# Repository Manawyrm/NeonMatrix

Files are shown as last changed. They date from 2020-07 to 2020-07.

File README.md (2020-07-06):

NeonMatrix
=============================

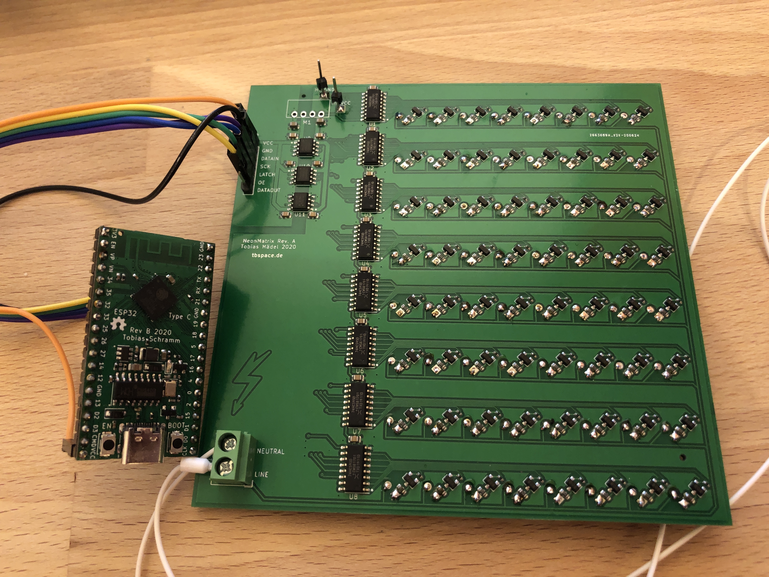
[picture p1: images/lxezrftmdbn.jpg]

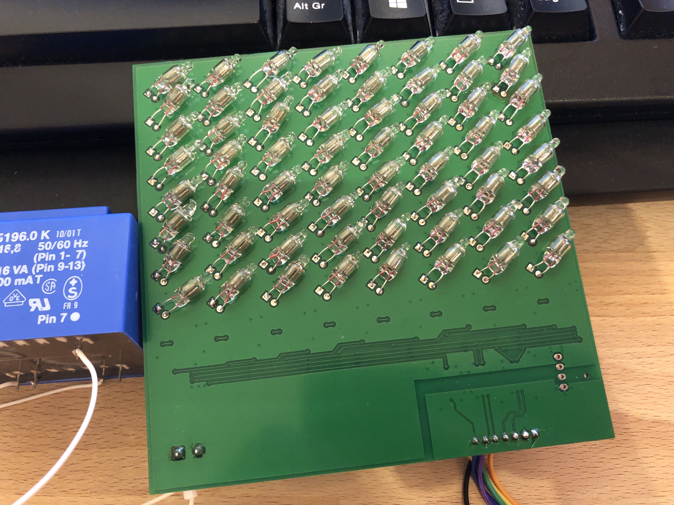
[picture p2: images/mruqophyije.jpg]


#### Overview

The NeonMatrix 8x8 matrix uses common neon indicator bulbs to display simple graphics.  
They can be chained and controlled directly via SPI.  

Operating voltage is about ~70V AC.  
The circuit is **pretty dangerous**, all neon bulbs have high voltages on their legs, the 74HC595 shift registers are floating at mains/AC potential.  
Safe data in/output is realized through 3 ADUM1200 digital isolator ICs and one B0505S DC-DC isolating converter. 

#### Additional info

[Firmware](https://github.com/Manawyrm/NeonMatrix-Firmware)  
[Schematic](https://github.com/Manawyrm/NeonMatrix/blob/master/Schematic.pdf)

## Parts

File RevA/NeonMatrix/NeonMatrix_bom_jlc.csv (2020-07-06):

Comment | Designator | Footprint | LCSC Part #
100n | C1,C2,C3,C4,C15,C16,C6,C7,C8,C9,C10,C11,C12,C13 | C_0805_2012Metric | C49678
22u | C5,C14 | C_0805_2012Metric | C45783
Q_TRIAC_A1GA2 | D1,D2,D3,D4,D5,D6,D7,D8,D9,D10,D11,D12,D13,D14,D15,D16,D17,D18,D19,D20,D21,D22,D23,D24,D25,D26,D27,D28,D29,D30,D31,D32,D33,D34,D35,D36,D37,D38,D39,D40,D41,D42,D43,D44,D45,D46,D47,D48,D49,D50,D51,D52,D53,D54,D55,D56,D57,D58,D59,D60,D61,D62,D63,D64 | SOT-23 | C85116
33k | R1,R3,R5,R7,R9,R11,R13,R15,R17,R19,R21,R23,R25,R27,R29,R31,R33,R35,R37,R39,R41,R43,R45,R47,R49,R51,R53,R55,R57,R59,R61,R63,R65,R67,R69,R71,R73,R75,R77,R79,R81,R83,R85,R87,R89,R91,R93,R95,R97,R99,R101,R103,R105,R107,R109,R111,R113,R115,R117,R119,R121,R123,R125,R127 | R_0402_1005Metric | C25779
33k | R2,R4,R6,R8,R10,R12,R14,R16,R18,R20,R22,R24,R26,R28,R30,R32,R34,R36,R38,R40,R42,R44,R46,R48,R50,R52,R54,R56,R58,R60,R62,R64,R66,R68,R70,R72,R74,R76,R78,R80,R82,R84,R86,R88,R90,R92,R94,R96,R98,R100,R102,R104,R106,R108,R110,R112,R114,R116,R118,R120,R122,R124,R126,R128 | R_0603_1608Metric | C4216
74HC595 | U1,U2,U3,U4,U5,U6,U7,U8 | SOIC-16_3.9x9.9mm_P1.27mm | C5947
ADuM1200AR | U9,U10,U11 | SOIC-8_3.9x4.9mm_P1.27mm | C15219

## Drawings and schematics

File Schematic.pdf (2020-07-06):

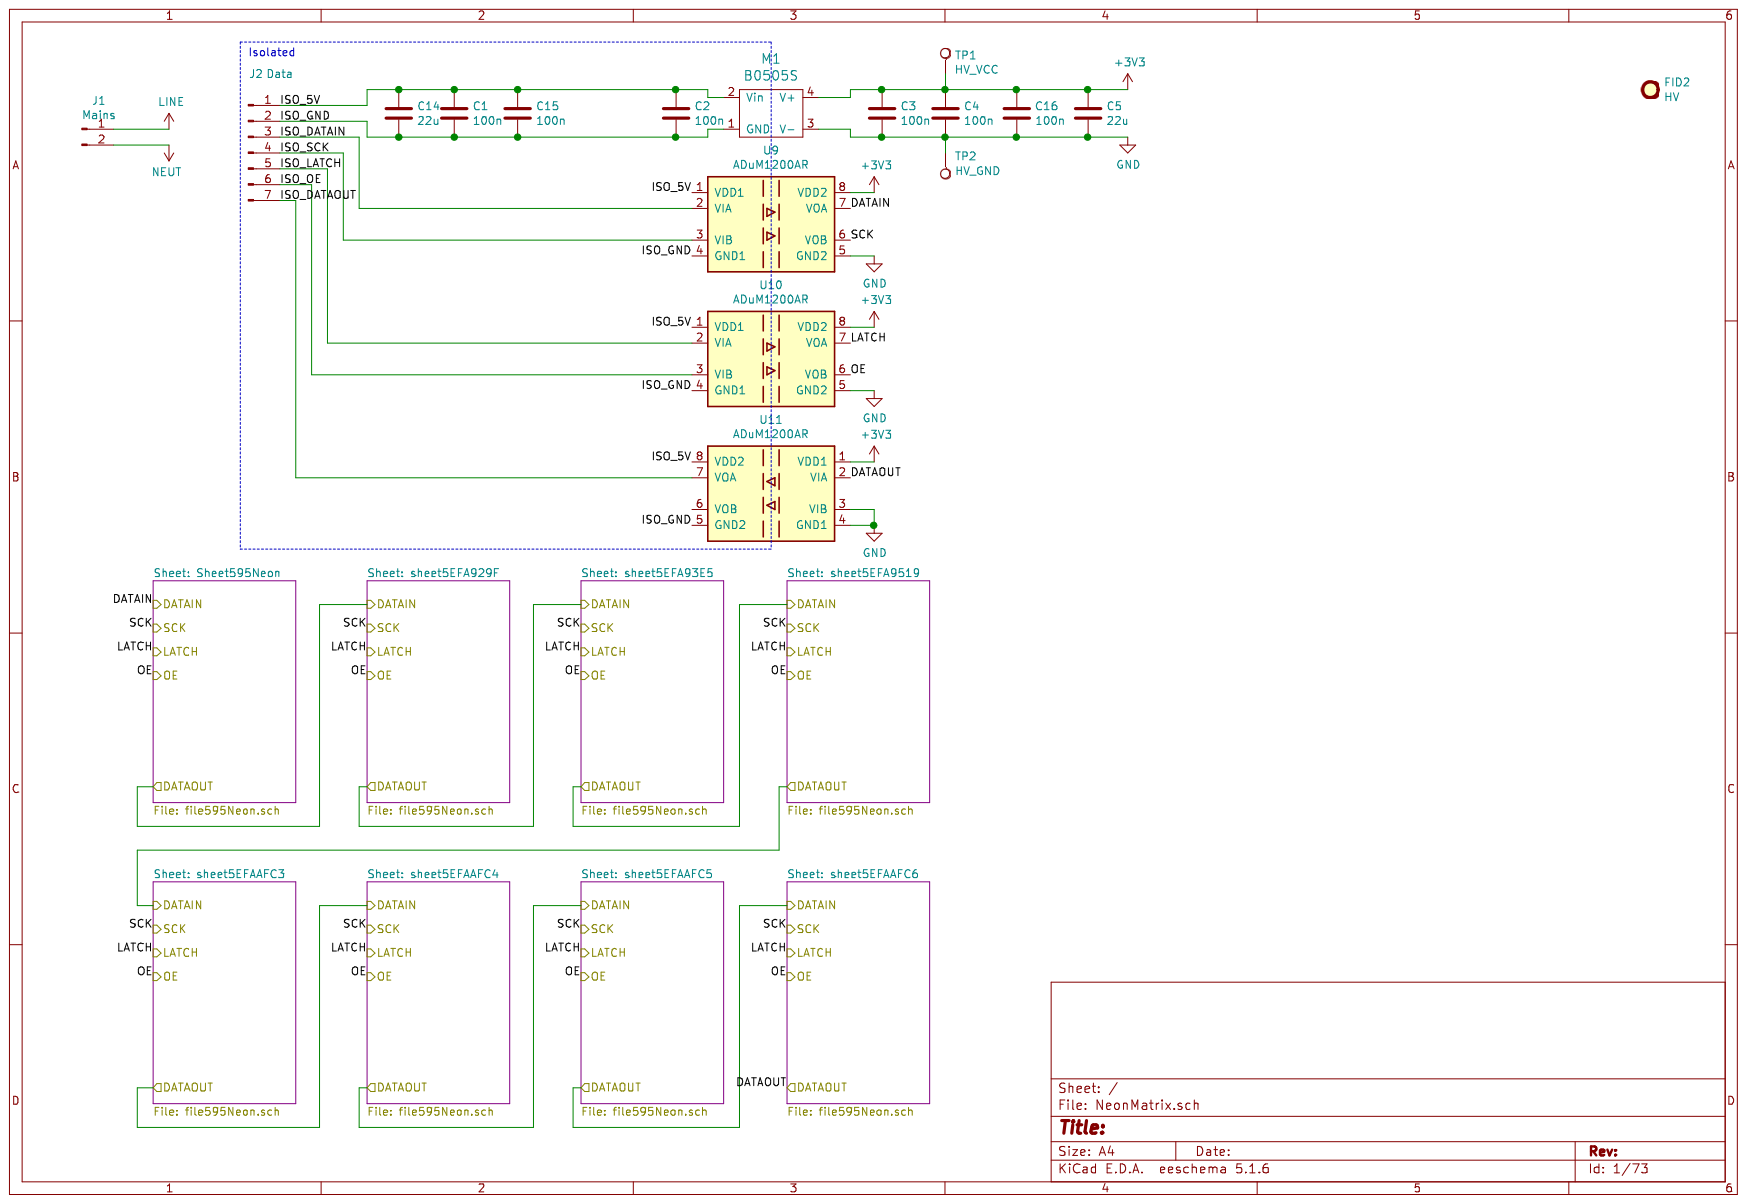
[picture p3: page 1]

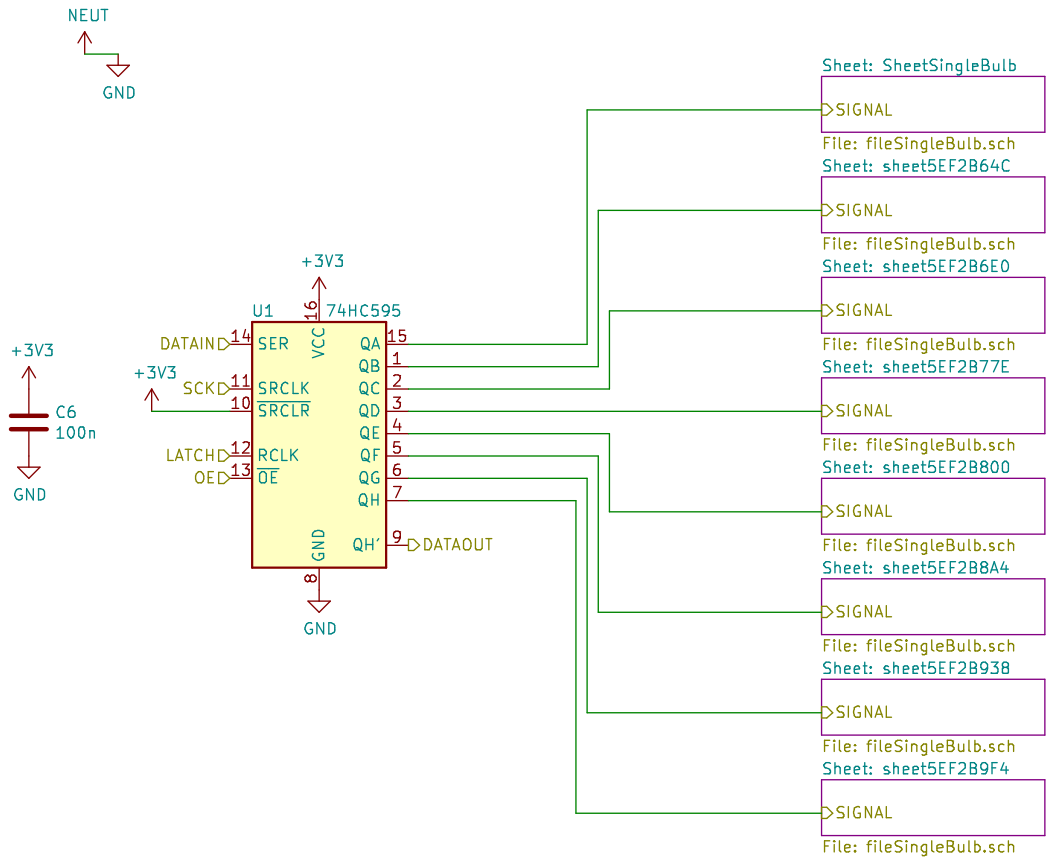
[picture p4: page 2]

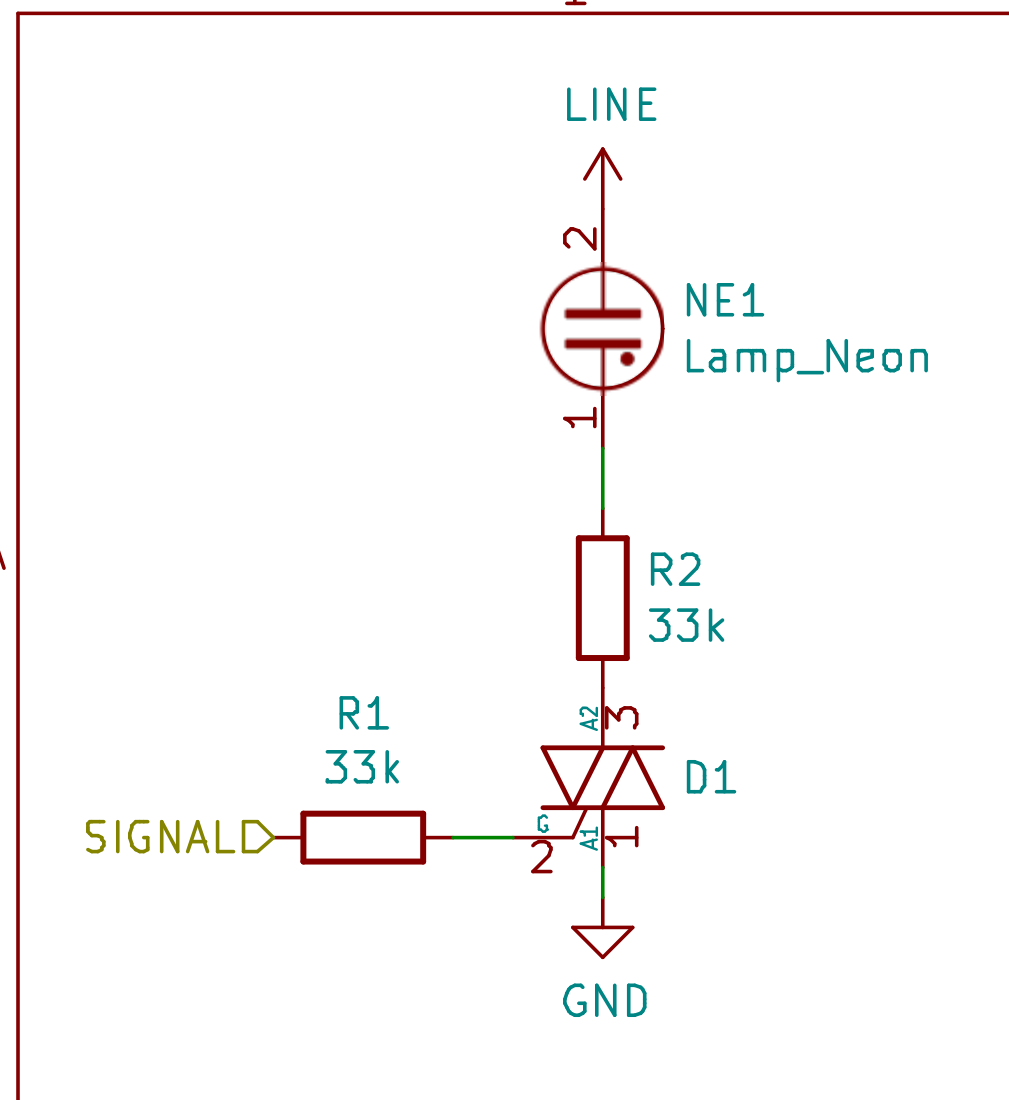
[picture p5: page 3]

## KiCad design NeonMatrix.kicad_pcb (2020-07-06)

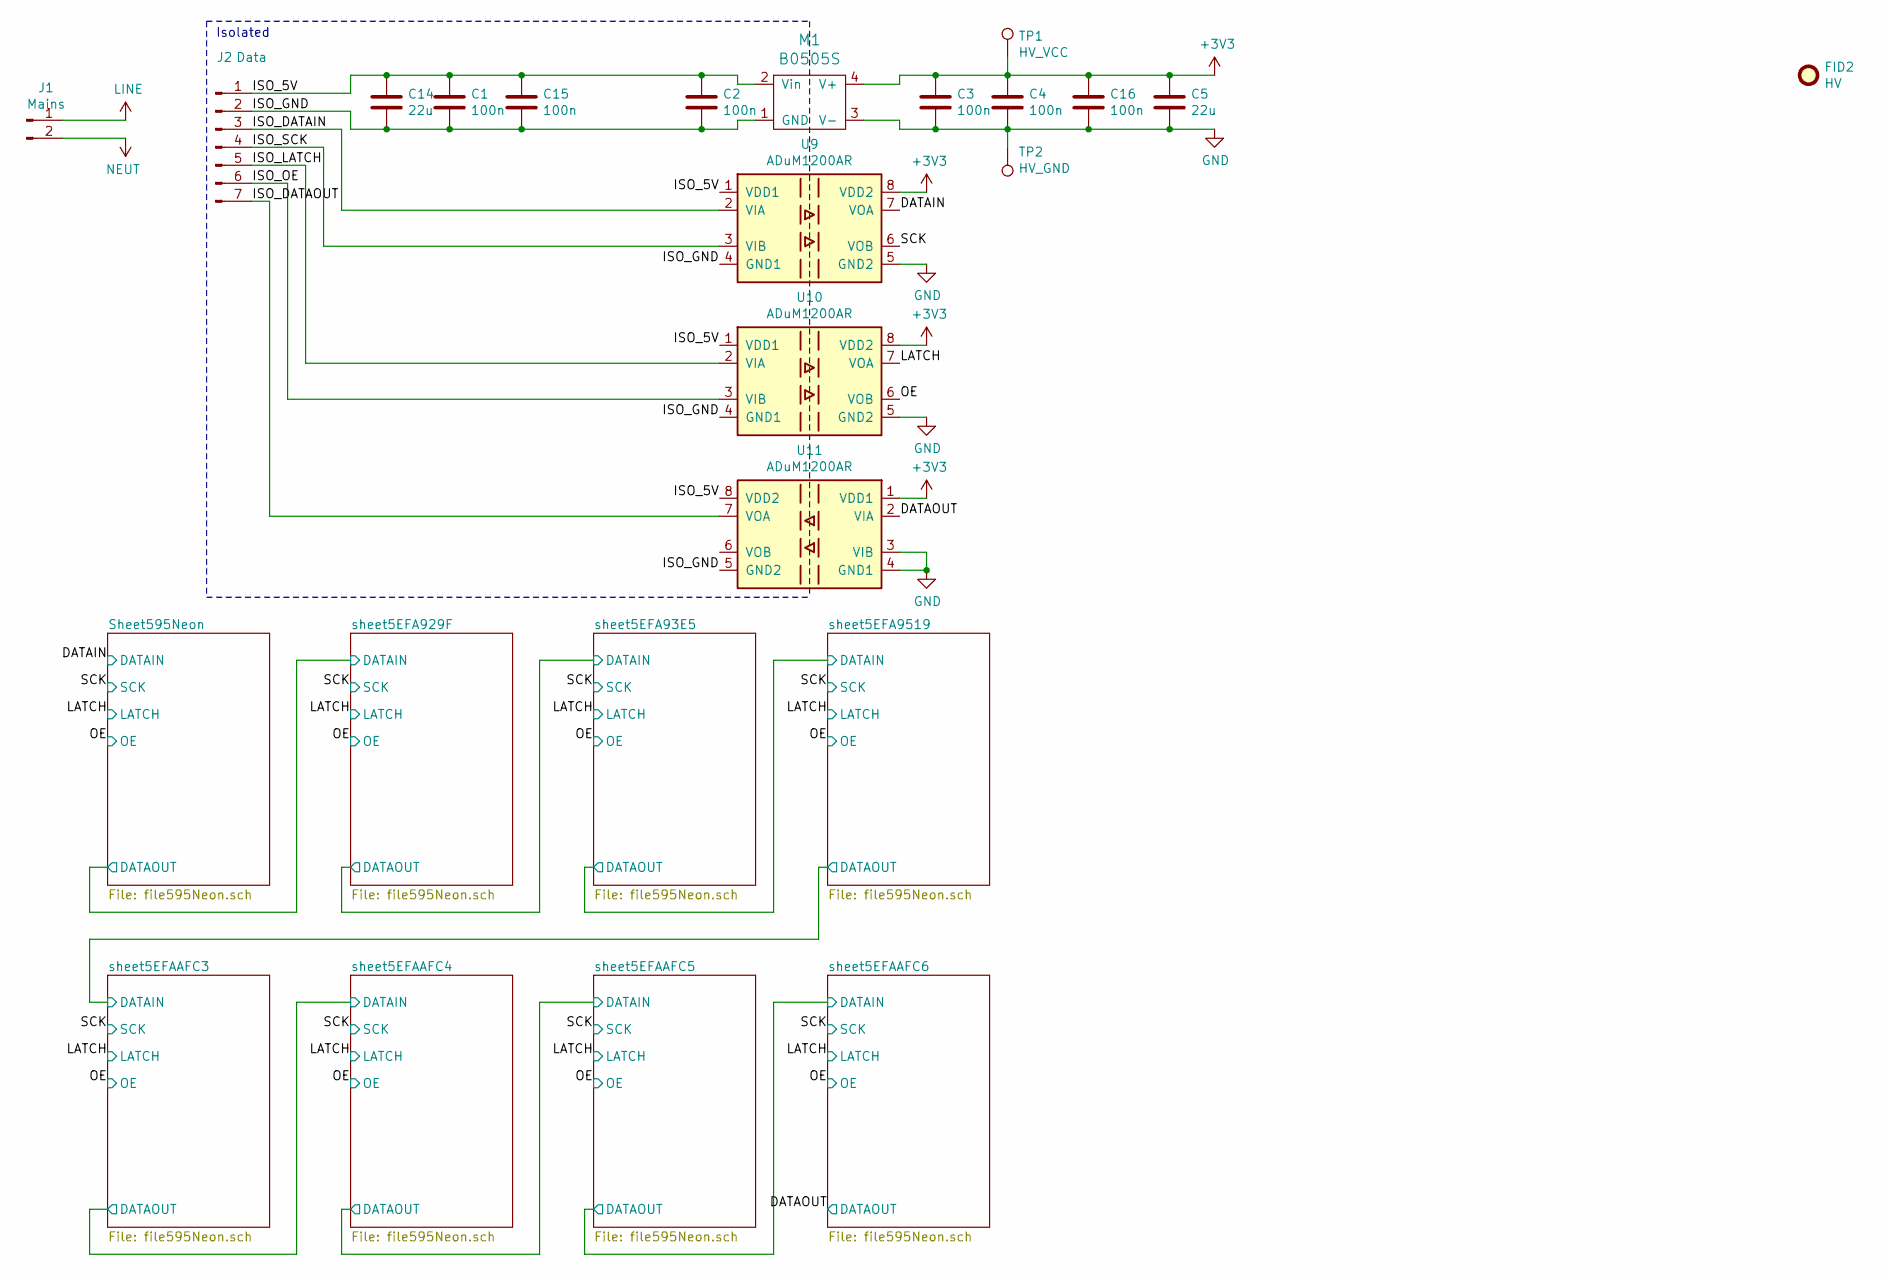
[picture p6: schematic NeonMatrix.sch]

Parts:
C1, C2, C3, C4, C15, C16: 100n; C_0805_2012Metric; LCSC C49678
C5, C14: 22u; C_0805_2012Metric; LCSC C45783
FID2: HV; Symbol_HighVoltage_Type1_CopperTop_Big
J1: Mains; TerminalBlock_RND_205-00001_1x02_P5.00mm_Horizontal
J2: Data; PinHeader_1x07_P2.54mm_Vertical
M1: B0505S; M_DCDC_SIP4
TP1: HV_VCC; TestPoint_Pad_2.0x2.0mm
TP2: HV_GND; TestPoint_Pad_2.0x2.0mm
U9, U10, U11: ADuM1200AR; SOIC-8_3.9x4.9mm_P1.27mm; LCSC C15219

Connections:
+3V3: C3.1, C4.1, C5.1, C16.1, M1.4 (V+), TP1.1, U9.8 (VDD2), U10.8 (VDD2), U11.1 (VDD1); also elsewhere on the board
/DATAIN: U9.7 (VOA); also elsewhere on the board
/DATAOUT: U11.2 (VIA); also elsewhere on the board
/ISO_5V: C1.1, C2.1, C14.1, C15.1, J2.1, M1.2 (Vin), U9.1 (VDD1), U10.1 (VDD1), U11.8 (VDD2)
/ISO_DATAIN: J2.3, U9.2 (VIA)
/ISO_DATAOUT: J2.7, U11.7 (VOA)
/ISO_GND: C1.2, C2.2, C14.2, C15.2, J2.2, M1.1 (GND), U9.4 (GND1), U10.4 (GND1), U11.5 (GND2)
/ISO_LATCH: J2.5, U10.2 (VIA)
/ISO_OE: J2.6, U10.3 (VIB)
/ISO_SCK: J2.4, U9.3 (VIB)
/LATCH: U10.7 (VOA); also elsewhere on the board
/OE: U10.6 (VOB); also elsewhere on the board
/SCK: U9.6 (VOB); also elsewhere on the board
GND: C3.2, C4.2, C5.2, C16.2, J1.2, M1.3 (V-), TP2.1, U9.5 (GND2), U10.5 (GND2), U11.3 (VIB), U11.4 (GND1); also elsewhere on the board
LINE: J1.1; also elsewhere on the board

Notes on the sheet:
Isolated

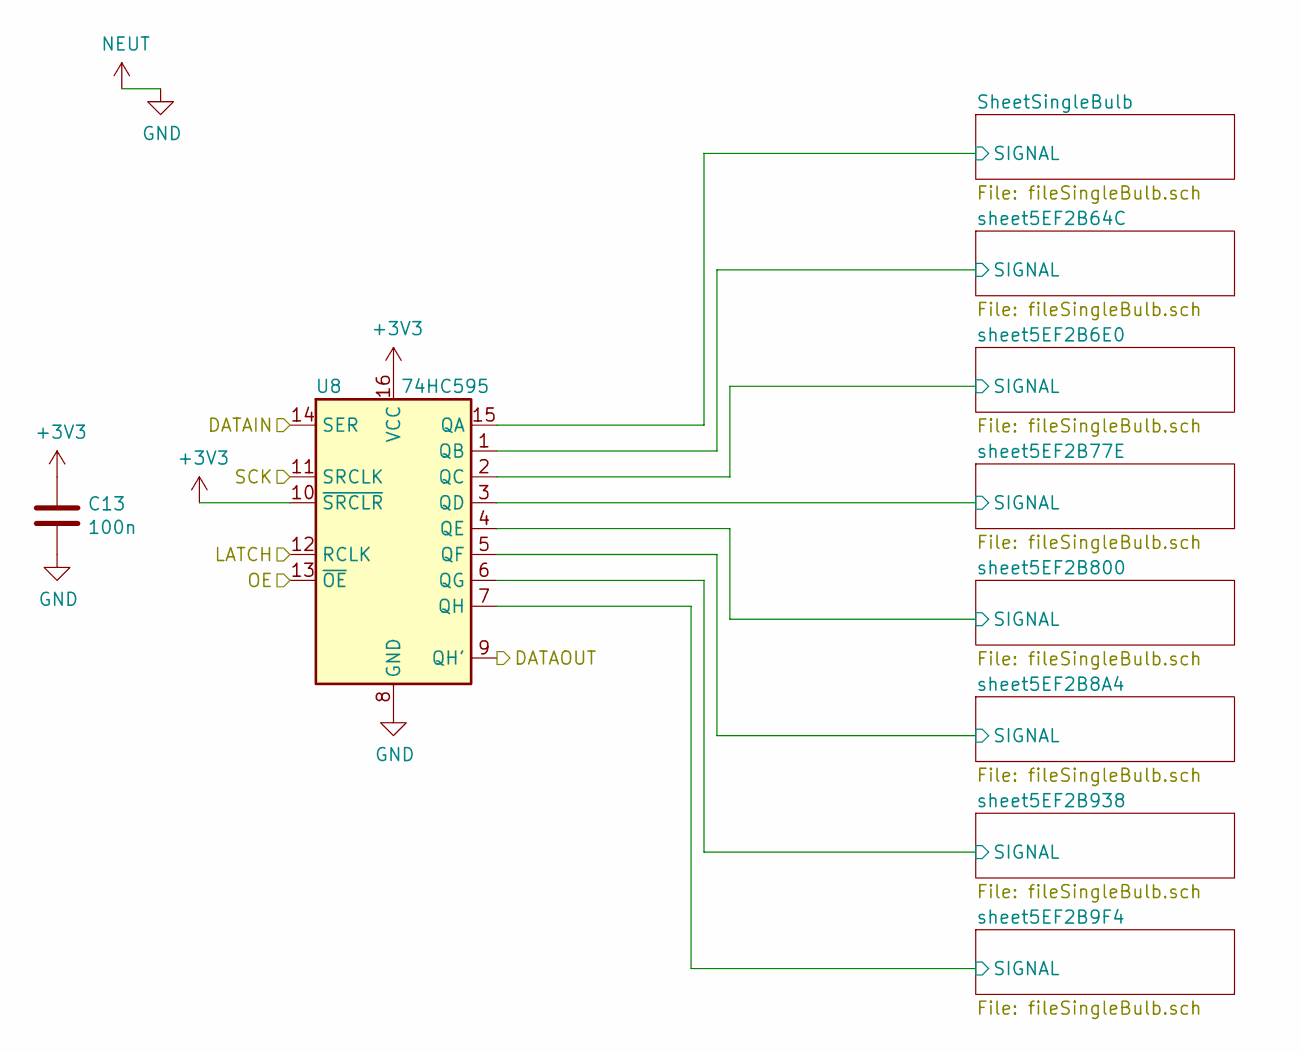
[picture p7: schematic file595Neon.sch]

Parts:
C7: 100n; C_0805_2012Metric; LCSC C49678
U1: 74HC595; SOIC-16_3.9x9.9mm_P1.27mm; LCSC C5947

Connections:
+3V3: C7.1, U1.10 (~SRCLR), U1.16 (VCC); also elsewhere on the board
/DATAIN: U1.14 (SER); also elsewhere on the board
/LATCH: U1.12 (RCLK); also elsewhere on the board
/OE: U1.13 (~OE); also elsewhere on the board
/SCK: U1.11 (SRCLK); also elsewhere on the board
/Sheet595Neon/SheetSingleBulb/SIGNAL: U1.15 (QA); also elsewhere on the board
/Sheet595Neon/sheet5EF2B6E0/SIGNAL: U1.2 (QC); also elsewhere on the board
/Sheet595Neon/sheet5EF2B8A4/SIGNAL: U1.5 (QF); also elsewhere on the board
/Sheet595Neon/sheet5EF2B9F4/SIGNAL: U1.7 (QH); also elsewhere on the board
/Sheet595Neon/sheet5EF2B64C/SIGNAL: U1.1 (QB); also elsewhere on the board
/Sheet595Neon/sheet5EF2B77E/SIGNAL: U1.3 (QD); also elsewhere on the board
/Sheet595Neon/sheet5EF2B800/SIGNAL: U1.4 (QE); also elsewhere on the board
/Sheet595Neon/sheet5EF2B938/SIGNAL: U1.6 (QG); also elsewhere on the board
/sheet5EFA929F/DATAIN: U1.9 (QH'); also elsewhere on the board
GND: C7.2, U1.8 (GND); also elsewhere on the board

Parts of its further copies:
C6, C8, C9, C10, C11, C12, C13: 100n; C_0805_2012Metric; LCSC C49678
U2, U3, U4, U5, U6, U7, U8: 74HC595; SOIC-16_3.9x9.9mm_P1.27mm; LCSC C5947

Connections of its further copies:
+3V3: C6.1, C8.1, C9.1, C10.1, C11.1, C12.1, C13.1, U2.10 (~SRCLR), U2.16 (VCC), U3.10 (~SRCLR), U3.16 (VCC), U4.10 (~SRCLR), U4.16 (VCC), U5.10 (~SRCLR), U5.16 (VCC), U6.10 (~SRCLR), U6.16 (VCC), U7.10 (~SRCLR), U7.16 (VCC), U8.10 (~SRCLR), U8.16 (VCC); also elsewhere on the board
/DATAOUT: U8.9 (QH'); also elsewhere on the board
/LATCH: U2.12 (RCLK), U3.12 (RCLK), U4.12 (RCLK), U5.12 (RCLK), U6.12 (RCLK), U7.12 (RCLK), U8.12 (RCLK); also elsewhere on the board
/OE: U2.13 (~OE), U3.13 (~OE), U4.13 (~OE), U5.13 (~OE), U6.13 (~OE), U7.13 (~OE), U8.13 (~OE); also elsewhere on the board
/SCK: U2.11 (SRCLK), U3.11 (SRCLK), U4.11 (SRCLK), U5.11 (SRCLK), U6.11 (SRCLK), U7.11 (SRCLK), U8.11 (SRCLK); also elsewhere on the board
/sheet5EFA93E5/DATAIN: U2.9 (QH'), U3.14 (SER)
/sheet5EFA93E5/SheetSingleBulb/SIGNAL: U3.15 (QA); also elsewhere on the board
/sheet5EFA93E5/sheet5EF2B6E0/SIGNAL: U3.2 (QC); also elsewhere on the board
/sheet5EFA93E5/sheet5EF2B8A4/SIGNAL: U3.5 (QF); also elsewhere on the board
/sheet5EFA93E5/sheet5EF2B9F4/SIGNAL: U3.7 (QH); also elsewhere on the board
/sheet5EFA93E5/sheet5EF2B64C/SIGNAL: U3.1 (QB); also elsewhere on the board
/sheet5EFA93E5/sheet5EF2B77E/SIGNAL: U3.3 (QD); also elsewhere on the board
/sheet5EFA93E5/sheet5EF2B800/SIGNAL: U3.4 (QE); also elsewhere on the board
/sheet5EFA93E5/sheet5EF2B938/SIGNAL: U3.6 (QG); also elsewhere on the board
/sheet5EFA929F/DATAIN: U2.14 (SER); also elsewhere on the board
/sheet5EFA929F/SheetSingleBulb/SIGNAL: U2.15 (QA); also elsewhere on the board
/sheet5EFA929F/sheet5EF2B6E0/SIGNAL: U2.2 (QC); also elsewhere on the board
/sheet5EFA929F/sheet5EF2B8A4/SIGNAL: U2.5 (QF); also elsewhere on the board
/sheet5EFA929F/sheet5EF2B9F4/SIGNAL: U2.7 (QH); also elsewhere on the board
/sheet5EFA929F/sheet5EF2B64C/SIGNAL: U2.1 (QB); also elsewhere on the board
/sheet5EFA929F/sheet5EF2B77E/SIGNAL: U2.3 (QD); also elsewhere on the board
/sheet5EFA929F/sheet5EF2B800/SIGNAL: U2.4 (QE); also elsewhere on the board
/sheet5EFA929F/sheet5EF2B938/SIGNAL: U2.6 (QG); also elsewhere on the board
/sheet5EFA9519/DATAIN: U3.9 (QH'), U4.14 (SER)
/sheet5EFA9519/SheetSingleBulb/SIGNAL: U4.15 (QA); also elsewhere on the board
/sheet5EFA9519/sheet5EF2B6E0/SIGNAL: U4.2 (QC); also elsewhere on the board
/sheet5EFA9519/sheet5EF2B8A4/SIGNAL: U4.5 (QF); also elsewhere on the board
/sheet5EFA9519/sheet5EF2B9F4/SIGNAL: U4.7 (QH); also elsewhere on the board
/sheet5EFA9519/sheet5EF2B64C/SIGNAL: U4.1 (QB); also elsewhere on the board
/sheet5EFA9519/sheet5EF2B77E/SIGNAL: U4.3 (QD); also elsewhere on the board
/sheet5EFA9519/sheet5EF2B800/SIGNAL: U4.4 (QE); also elsewhere on the board
/sheet5EFA9519/sheet5EF2B938/SIGNAL: U4.6 (QG); also elsewhere on the board
/sheet5EFAAFC3/DATAIN: U4.9 (QH'), U5.14 (SER)
/sheet5EFAAFC3/SheetSingleBulb/SIGNAL: U5.15 (QA); also elsewhere on the board
/sheet5EFAAFC3/sheet5EF2B6E0/SIGNAL: U5.2 (QC); also elsewhere on the board
/sheet5EFAAFC3/sheet5EF2B8A4/SIGNAL: U5.5 (QF); also elsewhere on the board
/sheet5EFAAFC3/sheet5EF2B9F4/SIGNAL: U5.7 (QH); also elsewhere on the board
/sheet5EFAAFC3/sheet5EF2B64C/SIGNAL: U5.1 (QB); also elsewhere on the board
/sheet5EFAAFC3/sheet5EF2B77E/SIGNAL: U5.3 (QD); also elsewhere on the board
/sheet5EFAAFC3/sheet5EF2B800/SIGNAL: U5.4 (QE); also elsewhere on the board
/sheet5EFAAFC3/sheet5EF2B938/SIGNAL: U5.6 (QG); also elsewhere on the board
/sheet5EFAAFC4/DATAIN: U5.9 (QH'), U6.14 (SER)
/sheet5EFAAFC4/SheetSingleBulb/SIGNAL: U6.15 (QA); also elsewhere on the board
/sheet5EFAAFC4/sheet5EF2B6E0/SIGNAL: U6.2 (QC); also elsewhere on the board
/sheet5EFAAFC4/sheet5EF2B8A4/SIGNAL: U6.5 (QF); also elsewhere on the board
/sheet5EFAAFC4/sheet5EF2B9F4/SIGNAL: U6.7 (QH); also elsewhere on the board
/sheet5EFAAFC4/sheet5EF2B64C/SIGNAL: U6.1 (QB); also elsewhere on the board
/sheet5EFAAFC4/sheet5EF2B77E/SIGNAL: U6.3 (QD); also elsewhere on the board
/sheet5EFAAFC4/sheet5EF2B800/SIGNAL: U6.4 (QE); also elsewhere on the board
/sheet5EFAAFC4/sheet5EF2B938/SIGNAL: U6.6 (QG); also elsewhere on the board
/sheet5EFAAFC5/DATAIN: U6.9 (QH'), U7.14 (SER)
/sheet5EFAAFC5/SheetSingleBulb/SIGNAL: U7.15 (QA); also elsewhere on the board
/sheet5EFAAFC5/sheet5EF2B6E0/SIGNAL: U7.2 (QC); also elsewhere on the board
/sheet5EFAAFC5/sheet5EF2B8A4/SIGNAL: U7.5 (QF); also elsewhere on the board
/sheet5EFAAFC5/sheet5EF2B9F4/SIGNAL: U7.7 (QH); also elsewhere on the board
/sheet5EFAAFC5/sheet5EF2B64C/SIGNAL: U7.1 (QB); also elsewhere on the board
/sheet5EFAAFC5/sheet5EF2B77E/SIGNAL: U7.3 (QD); also elsewhere on the board
/sheet5EFAAFC5/sheet5EF2B800/SIGNAL: U7.4 (QE); also elsewhere on the board
/sheet5EFAAFC5/sheet5EF2B938/SIGNAL: U7.6 (QG); also elsewhere on the board
/sheet5EFAAFC6/DATAIN: U7.9 (QH'), U8.14 (SER)
/sheet5EFAAFC6/SheetSingleBulb/SIGNAL: U8.15 (QA); also elsewhere on the board
/sheet5EFAAFC6/sheet5EF2B6E0/SIGNAL: U8.2 (QC); also elsewhere on the board
/sheet5EFAAFC6/sheet5EF2B8A4/SIGNAL: U8.5 (QF); also elsewhere on the board
/sheet5EFAAFC6/sheet5EF2B9F4/SIGNAL: U8.7 (QH); also elsewhere on the board
/sheet5EFAAFC6/sheet5EF2B64C/SIGNAL: U8.1 (QB); also elsewhere on the board
/sheet5EFAAFC6/sheet5EF2B77E/SIGNAL: U8.3 (QD); also elsewhere on the board
/sheet5EFAAFC6/sheet5EF2B800/SIGNAL: U8.4 (QE); also elsewhere on the board
/sheet5EFAAFC6/sheet5EF2B938/SIGNAL: U8.6 (QG); also elsewhere on the board
GND: C6.2, C8.2, C9.2, C10.2, C11.2, C12.2, C13.2, U2.8 (GND), U3.8 (GND), U4.8 (GND), U5.8 (GND), U6.8 (GND), U7.8 (GND), U8.8 (GND); also elsewhere on the board

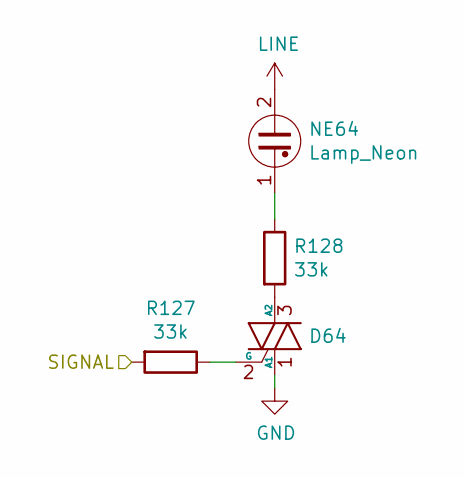
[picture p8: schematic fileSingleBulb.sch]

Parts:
D1: Q_TRIAC_A1GA2; SOT-23; LCSC C85116
NE1: Lamp_Neon; NeonBulb
R1: 33k; R_0402_1005Metric; LCSC C25779
R2: 33k; R_0603_1608Metric; LCSC C4216

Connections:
/Sheet595Neon/SheetSingleBulb/SIGNAL: R1.2; also elsewhere on the board
GND: D1.1 (A1); also elsewhere on the board
LINE: NE1.2; also elsewhere on the board
unnamed: D1.2 (G), R1.1
unnamed: D1.3 (A2), R2.2
unnamed: NE1.1, R2.1

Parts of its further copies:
D2, D3, D4, D5, D6, D7, D8, D9, D10, D11, D12, D13, D14, D15, D16, D17, D18, D19, D20, D21, D22, D23, D24, D25, D26, D27, D28, D29, D30, D31, D32, D33, D34, D35, D36, D37, D38, D39, D40, D41, D42, D43, D44, D45, D46, D47, D48, D49, D50, D51, D52, D53, D54, D55, D56, D57, D58, D59, D60, D61, D62, D63, D64: Q_TRIAC_A1GA2; SOT-23; LCSC C85116
NE2, NE3, NE4, NE5, NE6, NE7, NE8, NE9, NE10, NE11, NE12, NE13, NE14, NE15, NE16, NE17, NE18, NE19, NE20, NE21, NE22, NE23, NE24, NE25, NE26, NE27, NE28, NE29, NE30, NE31, NE32, NE33, NE34, NE35, NE36, NE37, NE38, NE39, NE40, NE41, NE42, NE43, NE44, NE45, NE46, NE47, NE48, NE49, NE50, NE51, NE52, NE53, NE54, NE55, NE56, NE57, NE58, NE59, NE60, NE61, NE62, NE63, NE64: Lamp_Neon; NeonBulb
R3, R5, R7, R9, R11, R13, R15, R17, R19, R21, R23, R25, R27, R29, R31, R33, R35, R37, R39, R41, R43, R45, R47, R49, R51, R53, R55, R57, R59, R61, R63, R65, R67, R69, R71, R73, R75, R77, R79, R81, R83, R85, R87, R89, R91, R93, R95, R97, R99, R101, R103, R105, R107, R109, R111, R113, R115, R117, R119, R121, R123, R125, R127: 33k; R_0402_1005Metric; LCSC C25779
R4, R6, R8, R10, R12, R14, R16, R18, R20, R22, R24, R26, R28, R30, R32, R34, R36, R38, R40, R42, R44, R46, R48, R50, R52, R54, R56, R58, R60, R62, R64, R66, R68, R70, R72, R74, R76, R78, R80, R82, R84, R86, R88, R90, R92, R94, R96, R98, R100, R102, R104, R106, R108, R110, R112, R114, R116, R118, R120, R122, R124, R126, R128: 33k; R_0603_1608Metric; LCSC C4216

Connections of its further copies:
/Sheet595Neon/sheet5EF2B6E0/SIGNAL: R5.2; also elsewhere on the board
/Sheet595Neon/sheet5EF2B8A4/SIGNAL: R11.2; also elsewhere on the board
/Sheet595Neon/sheet5EF2B9F4/SIGNAL: R15.2; also elsewhere on the board
/Sheet595Neon/sheet5EF2B64C/SIGNAL: R3.2; also elsewhere on the board
/Sheet595Neon/sheet5EF2B77E/SIGNAL: R7.2; also elsewhere on the board
/Sheet595Neon/sheet5EF2B800/SIGNAL: R9.2; also elsewhere on the board
/Sheet595Neon/sheet5EF2B938/SIGNAL: R13.2; also elsewhere on the board
/sheet5EFA93E5/SheetSingleBulb/SIGNAL: R33.2; also elsewhere on the board
/sheet5EFA93E5/sheet5EF2B6E0/SIGNAL: R37.2; also elsewhere on the board
/sheet5EFA93E5/sheet5EF2B8A4/SIGNAL: R43.2; also elsewhere on the board
/sheet5EFA93E5/sheet5EF2B9F4/SIGNAL: R47.2; also elsewhere on the board
/sheet5EFA93E5/sheet5EF2B64C/SIGNAL: R35.2; also elsewhere on the board
/sheet5EFA93E5/sheet5EF2B77E/SIGNAL: R39.2; also elsewhere on the board
/sheet5EFA93E5/sheet5EF2B800/SIGNAL: R41.2; also elsewhere on the board
/sheet5EFA93E5/sheet5EF2B938/SIGNAL: R45.2; also elsewhere on the board
/sheet5EFA929F/SheetSingleBulb/SIGNAL: R17.2; also elsewhere on the board
/sheet5EFA929F/sheet5EF2B6E0/SIGNAL: R21.2; also elsewhere on the board
/sheet5EFA929F/sheet5EF2B8A4/SIGNAL: R27.2; also elsewhere on the board
/sheet5EFA929F/sheet5EF2B9F4/SIGNAL: R31.2; also elsewhere on the board
/sheet5EFA929F/sheet5EF2B64C/SIGNAL: R19.2; also elsewhere on the board
/sheet5EFA929F/sheet5EF2B77E/SIGNAL: R23.2; also elsewhere on the board
/sheet5EFA929F/sheet5EF2B800/SIGNAL: R25.2; also elsewhere on the board
/sheet5EFA929F/sheet5EF2B938/SIGNAL: R29.2; also elsewhere on the board
/sheet5EFA9519/SheetSingleBulb/SIGNAL: R49.2; also elsewhere on the board
/sheet5EFA9519/sheet5EF2B6E0/SIGNAL: R53.2; also elsewhere on the board
/sheet5EFA9519/sheet5EF2B8A4/SIGNAL: R59.2; also elsewhere on the board
/sheet5EFA9519/sheet5EF2B9F4/SIGNAL: R63.2; also elsewhere on the board
/sheet5EFA9519/sheet5EF2B64C/SIGNAL: R51.2; also elsewhere on the board
/sheet5EFA9519/sheet5EF2B77E/SIGNAL: R55.2; also elsewhere on the board
/sheet5EFA9519/sheet5EF2B800/SIGNAL: R57.2; also elsewhere on the board
/sheet5EFA9519/sheet5EF2B938/SIGNAL: R61.2; also elsewhere on the board
/sheet5EFAAFC3/SheetSingleBulb/SIGNAL: R65.2; also elsewhere on the board
/sheet5EFAAFC3/sheet5EF2B6E0/SIGNAL: R69.2; also elsewhere on the board
/sheet5EFAAFC3/sheet5EF2B8A4/SIGNAL: R75.2; also elsewhere on the board
/sheet5EFAAFC3/sheet5EF2B9F4/SIGNAL: R79.2; also elsewhere on the board
/sheet5EFAAFC3/sheet5EF2B64C/SIGNAL: R67.2; also elsewhere on the board
/sheet5EFAAFC3/sheet5EF2B77E/SIGNAL: R71.2; also elsewhere on the board
/sheet5EFAAFC3/sheet5EF2B800/SIGNAL: R73.2; also elsewhere on the board
/sheet5EFAAFC3/sheet5EF2B938/SIGNAL: R77.2; also elsewhere on the board
/sheet5EFAAFC4/SheetSingleBulb/SIGNAL: R81.2; also elsewhere on the board
/sheet5EFAAFC4/sheet5EF2B6E0/SIGNAL: R85.2; also elsewhere on the board
/sheet5EFAAFC4/sheet5EF2B8A4/SIGNAL: R91.2; also elsewhere on the board
/sheet5EFAAFC4/sheet5EF2B9F4/SIGNAL: R95.2; also elsewhere on the board
/sheet5EFAAFC4/sheet5EF2B64C/SIGNAL: R83.2; also elsewhere on the board
/sheet5EFAAFC4/sheet5EF2B77E/SIGNAL: R87.2; also elsewhere on the board
/sheet5EFAAFC4/sheet5EF2B800/SIGNAL: R89.2; also elsewhere on the board
/sheet5EFAAFC4/sheet5EF2B938/SIGNAL: R93.2; also elsewhere on the board
/sheet5EFAAFC5/SheetSingleBulb/SIGNAL: R97.2; also elsewhere on the board
/sheet5EFAAFC5/sheet5EF2B6E0/SIGNAL: R101.2; also elsewhere on the board
/sheet5EFAAFC5/sheet5EF2B8A4/SIGNAL: R107.2; also elsewhere on the board
/sheet5EFAAFC5/sheet5EF2B9F4/SIGNAL: R111.2; also elsewhere on the board
/sheet5EFAAFC5/sheet5EF2B64C/SIGNAL: R99.2; also elsewhere on the board
/sheet5EFAAFC5/sheet5EF2B77E/SIGNAL: R103.2; also elsewhere on the board
/sheet5EFAAFC5/sheet5EF2B800/SIGNAL: R105.2; also elsewhere on the board
/sheet5EFAAFC5/sheet5EF2B938/SIGNAL: R109.2; also elsewhere on the board
/sheet5EFAAFC6/SheetSingleBulb/SIGNAL: R113.2; also elsewhere on the board
/sheet5EFAAFC6/sheet5EF2B6E0/SIGNAL: R117.2; also elsewhere on the board
/sheet5EFAAFC6/sheet5EF2B8A4/SIGNAL: R123.2; also elsewhere on the board
/sheet5EFAAFC6/sheet5EF2B9F4/SIGNAL: R127.2; also elsewhere on the board
/sheet5EFAAFC6/sheet5EF2B64C/SIGNAL: R115.2; also elsewhere on the board
/sheet5EFAAFC6/sheet5EF2B77E/SIGNAL: R119.2; also elsewhere on the board
/sheet5EFAAFC6/sheet5EF2B800/SIGNAL: R121.2; also elsewhere on the board
/sheet5EFAAFC6/sheet5EF2B938/SIGNAL: R125.2; also elsewhere on the board
GND: D2.1 (A1), D3.1 (A1), D4.1 (A1), D5.1 (A1), D6.1 (A1), D7.1 (A1), D8.1 (A1), D9.1 (A1), D10.1 (A1), D11.1 (A1), D12.1 (A1), D13.1 (A1), D14.1 (A1), D15.1 (A1), D16.1 (A1), D17.1 (A1), D18.1 (A1), D19.1 (A1), D20.1 (A1), D21.1 (A1), D22.1 (A1), D23.1 (A1), D24.1 (A1), D25.1 (A1), D26.1 (A1), D27.1 (A1), D28.1 (A1), D29.1 (A1), D30.1 (A1), D31.1 (A1), D32.1 (A1), D33.1 (A1), D34.1 (A1), D35.1 (A1), D36.1 (A1), D37.1 (A1), D38.1 (A1), D39.1 (A1), D40.1 (A1), D41.1 (A1), D42.1 (A1), D43.1 (A1), D44.1 (A1), D45.1 (A1), D46.1 (A1), D47.1 (A1), D48.1 (A1), D49.1 (A1), D50.1 (A1), D51.1 (A1), D52.1 (A1), D53.1 (A1), D54.1 (A1), D55.1 (A1), D56.1 (A1), D57.1 (A1), D58.1 (A1), D59.1 (A1), D60.1 (A1), D61.1 (A1), D62.1 (A1), D63.1 (A1), D64.1 (A1); also elsewhere on the board
LINE: NE2.2, NE3.2, NE4.2, NE5.2, NE6.2, NE7.2, NE8.2, NE9.2, NE10.2, NE11.2, NE12.2, NE13.2, NE14.2, NE15.2, NE16.2, NE17.2, NE18.2, NE19.2, NE20.2, NE21.2, NE22.2, NE23.2, NE24.2, NE25.2, NE26.2, NE27.2, NE28.2, NE29.2, NE30.2, NE31.2, NE32.2, NE33.2, NE34.2, NE35.2, NE36.2, NE37.2, NE38.2, NE39.2, NE40.2, NE41.2, NE42.2, NE43.2, NE44.2, NE45.2, NE46.2, NE47.2, NE48.2, NE49.2, NE50.2, NE51.2, NE52.2, NE53.2, NE54.2, NE55.2, NE56.2, NE57.2, NE58.2, NE59.2, NE60.2, NE61.2, NE62.2, NE63.2, NE64.2; also elsewhere on the board
unnamed: D2.2 (G), R3.1
unnamed: D2.3 (A2), R4.2
unnamed: D3.2 (G), R5.1
unnamed: D3.3 (A2), R6.2
unnamed: D4.2 (G), R7.1
unnamed: D4.3 (A2), R8.2
unnamed: D5.2 (G), R9.1
unnamed: D5.3 (A2), R10.2
unnamed: D6.2 (G), R11.1
unnamed: D6.3 (A2), R12.2
unnamed: D7.2 (G), R13.1
unnamed: D7.3 (A2), R14.2
unnamed: D8.2 (G), R15.1
unnamed: D8.3 (A2), R16.2
unnamed: D9.2 (G), R17.1
unnamed: D9.3 (A2), R18.2
unnamed: D10.2 (G), R19.1
unnamed: D10.3 (A2), R20.2
unnamed: D11.2 (G), R21.1
unnamed: D11.3 (A2), R22.2
unnamed: D12.2 (G), R23.1
unnamed: D12.3 (A2), R24.2
unnamed: D13.2 (G), R25.1
unnamed: D13.3 (A2), R26.2
unnamed: D14.2 (G), R27.1
unnamed: D14.3 (A2), R28.2
unnamed: D15.2 (G), R29.1
unnamed: D15.3 (A2), R30.2
unnamed: D16.2 (G), R31.1
unnamed: D16.3 (A2), R32.2
unnamed: D17.2 (G), R33.1
unnamed: D17.3 (A2), R34.2
unnamed: D18.2 (G), R35.1
unnamed: D18.3 (A2), R36.2
unnamed: D19.2 (G), R37.1
unnamed: D19.3 (A2), R38.2
unnamed: D20.2 (G), R39.1
unnamed: D20.3 (A2), R40.2
unnamed: D21.2 (G), R41.1
unnamed: D21.3 (A2), R42.2
unnamed: D22.2 (G), R43.1
unnamed: D22.3 (A2), R44.2
unnamed: D23.2 (G), R45.1
unnamed: D23.3 (A2), R46.2
unnamed: D24.2 (G), R47.1
unnamed: D24.3 (A2), R48.2
unnamed: D25.2 (G), R49.1
unnamed: D25.3 (A2), R50.2
unnamed: D26.2 (G), R51.1
unnamed: D26.3 (A2), R52.2
unnamed: D27.2 (G), R53.1
unnamed: D27.3 (A2), R54.2
unnamed: D28.2 (G), R55.1
unnamed: D28.3 (A2), R56.2
unnamed: D29.2 (G), R57.1
unnamed: D29.3 (A2), R58.2
unnamed: D30.2 (G), R59.1
unnamed: D30.3 (A2), R60.2
unnamed: D31.2 (G), R61.1
unnamed: D31.3 (A2), R62.2
unnamed: D32.2 (G), R63.1
unnamed: D32.3 (A2), R64.2
unnamed: D33.2 (G), R65.1
unnamed: D33.3 (A2), R66.2
unnamed: D34.2 (G), R67.1
unnamed: D34.3 (A2), R68.2
unnamed: D35.2 (G), R69.1
unnamed: D35.3 (A2), R70.2
unnamed: D36.2 (G), R71.1
unnamed: D36.3 (A2), R72.2
unnamed: D37.2 (G), R73.1
unnamed: D37.3 (A2), R74.2
unnamed: D38.2 (G), R75.1
unnamed: D38.3 (A2), R76.2
unnamed: D39.2 (G), R77.1
unnamed: D39.3 (A2), R78.2
unnamed: D40.2 (G), R79.1
unnamed: D40.3 (A2), R80.2
unnamed: D41.2 (G), R81.1
unnamed: D41.3 (A2), R82.2
unnamed: D42.2 (G), R83.1
unnamed: D42.3 (A2), R84.2
unnamed: D43.2 (G), R85.1
unnamed: D43.3 (A2), R86.2
unnamed: D44.2 (G), R87.1
unnamed: D44.3 (A2), R88.2
unnamed: D45.2 (G), R89.1
unnamed: D45.3 (A2), R90.2
unnamed: D46.2 (G), R91.1
unnamed: D46.3 (A2), R92.2
unnamed: D47.2 (G), R93.1
unnamed: D47.3 (A2), R94.2
unnamed: D48.2 (G), R95.1
unnamed: D48.3 (A2), R96.2
unnamed: D49.2 (G), R97.1
unnamed: D49.3 (A2), R98.2
unnamed: D50.2 (G), R99.1
unnamed: D50.3 (A2), R100.2
unnamed: D51.2 (G), R101.1
unnamed: D51.3 (A2), R102.2
unnamed: D52.2 (G), R103.1
unnamed: D52.3 (A2), R104.2
unnamed: D53.2 (G), R105.1
unnamed: D53.3 (A2), R106.2
unnamed: D54.2 (G), R107.1
unnamed: D54.3 (A2), R108.2
unnamed: D55.2 (G), R109.1
unnamed: D55.3 (A2), R110.2
unnamed: D56.2 (G), R111.1
unnamed: D56.3 (A2), R112.2
unnamed: D57.2 (G), R113.1
unnamed: D57.3 (A2), R114.2
unnamed: D58.2 (G), R115.1
unnamed: D58.3 (A2), R116.2
unnamed: D59.2 (G), R117.1
unnamed: D59.3 (A2), R118.2
unnamed: D60.2 (G), R119.1
unnamed: D60.3 (A2), R120.2
unnamed: D61.2 (G), R121.1
unnamed: D61.3 (A2), R122.2
unnamed: D62.2 (G), R123.1
unnamed: D62.3 (A2), R124.2
unnamed: D63.2 (G), R125.1
unnamed: D63.3 (A2), R126.2
unnamed: D64.2 (G), R127.1
unnamed: D64.3 (A2), R128.2
unnamed: NE2.1, R4.1
unnamed: NE3.1, R6.1
unnamed: NE4.1, R8.1
unnamed: NE5.1, R10.1
unnamed: NE6.1, R12.1
unnamed: NE7.1, R14.1
unnamed: NE8.1, R16.1
unnamed: NE9.1, R18.1
unnamed: NE10.1, R20.1
unnamed: NE11.1, R22.1
unnamed: NE12.1, R24.1
unnamed: NE13.1, R26.1
unnamed: NE14.1, R28.1
unnamed: NE15.1, R30.1
unnamed: NE16.1, R32.1
unnamed: NE17.1, R34.1
unnamed: NE18.1, R36.1
unnamed: NE19.1, R38.1
unnamed: NE20.1, R40.1
unnamed: NE21.1, R42.1
unnamed: NE22.1, R44.1
unnamed: NE23.1, R46.1
unnamed: NE24.1, R48.1
unnamed: NE25.1, R50.1
unnamed: NE26.1, R52.1
unnamed: NE27.1, R54.1
unnamed: NE28.1, R56.1
unnamed: NE29.1, R58.1
unnamed: NE30.1, R60.1
unnamed: NE31.1, R62.1
unnamed: NE32.1, R64.1
unnamed: NE33.1, R66.1
unnamed: NE34.1, R68.1
unnamed: NE35.1, R70.1
unnamed: NE36.1, R72.1
unnamed: NE37.1, R74.1
unnamed: NE38.1, R76.1
unnamed: NE39.1, R78.1
unnamed: NE40.1, R80.1
unnamed: NE41.1, R82.1
unnamed: NE42.1, R84.1
unnamed: NE43.1, R86.1
unnamed: NE44.1, R88.1
unnamed: NE45.1, R90.1
unnamed: NE46.1, R92.1
unnamed: NE47.1, R94.1
unnamed: NE48.1, R96.1
unnamed: NE49.1, R98.1
unnamed: NE50.1, R100.1
unnamed: NE51.1, R102.1
unnamed: NE52.1, R104.1
unnamed: NE53.1, R106.1
unnamed: NE54.1, R108.1
unnamed: NE55.1, R110.1
unnamed: NE56.1, R112.1
unnamed: NE57.1, R114.1
unnamed: NE58.1, R116.1
unnamed: NE59.1, R118.1
unnamed: NE60.1, R120.1
unnamed: NE61.1, R122.1
unnamed: NE62.1, R124.1
unnamed: NE63.1, R126.1
unnamed: NE64.1, R128.1

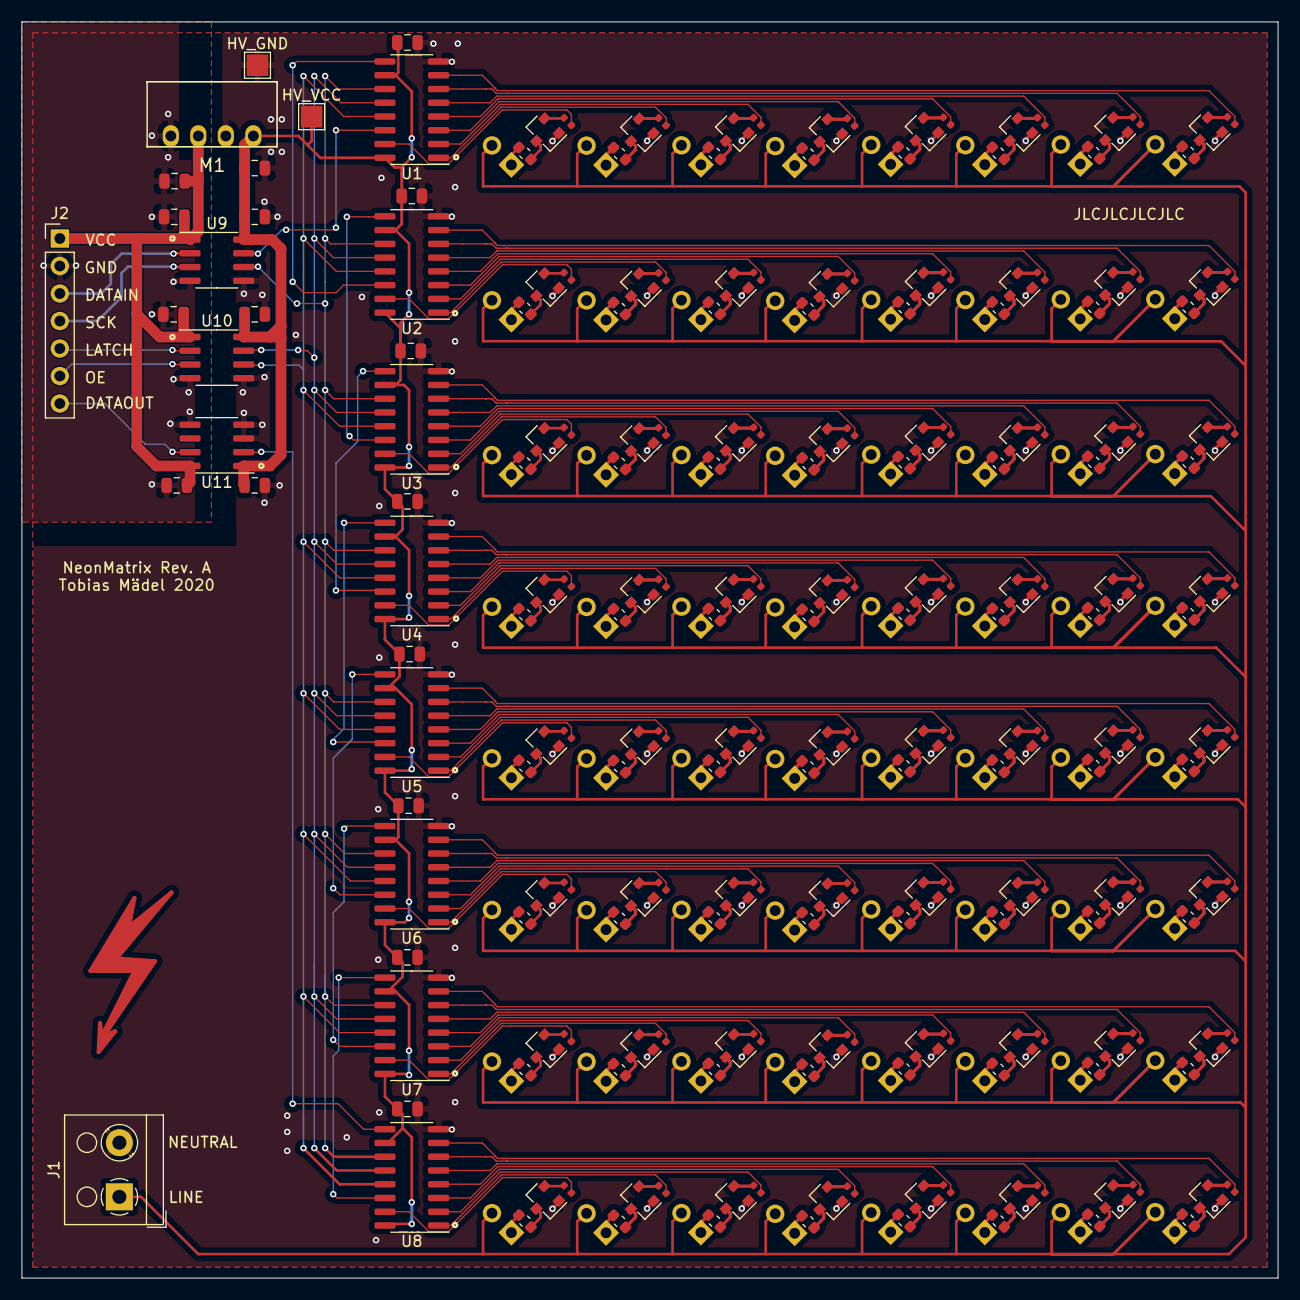
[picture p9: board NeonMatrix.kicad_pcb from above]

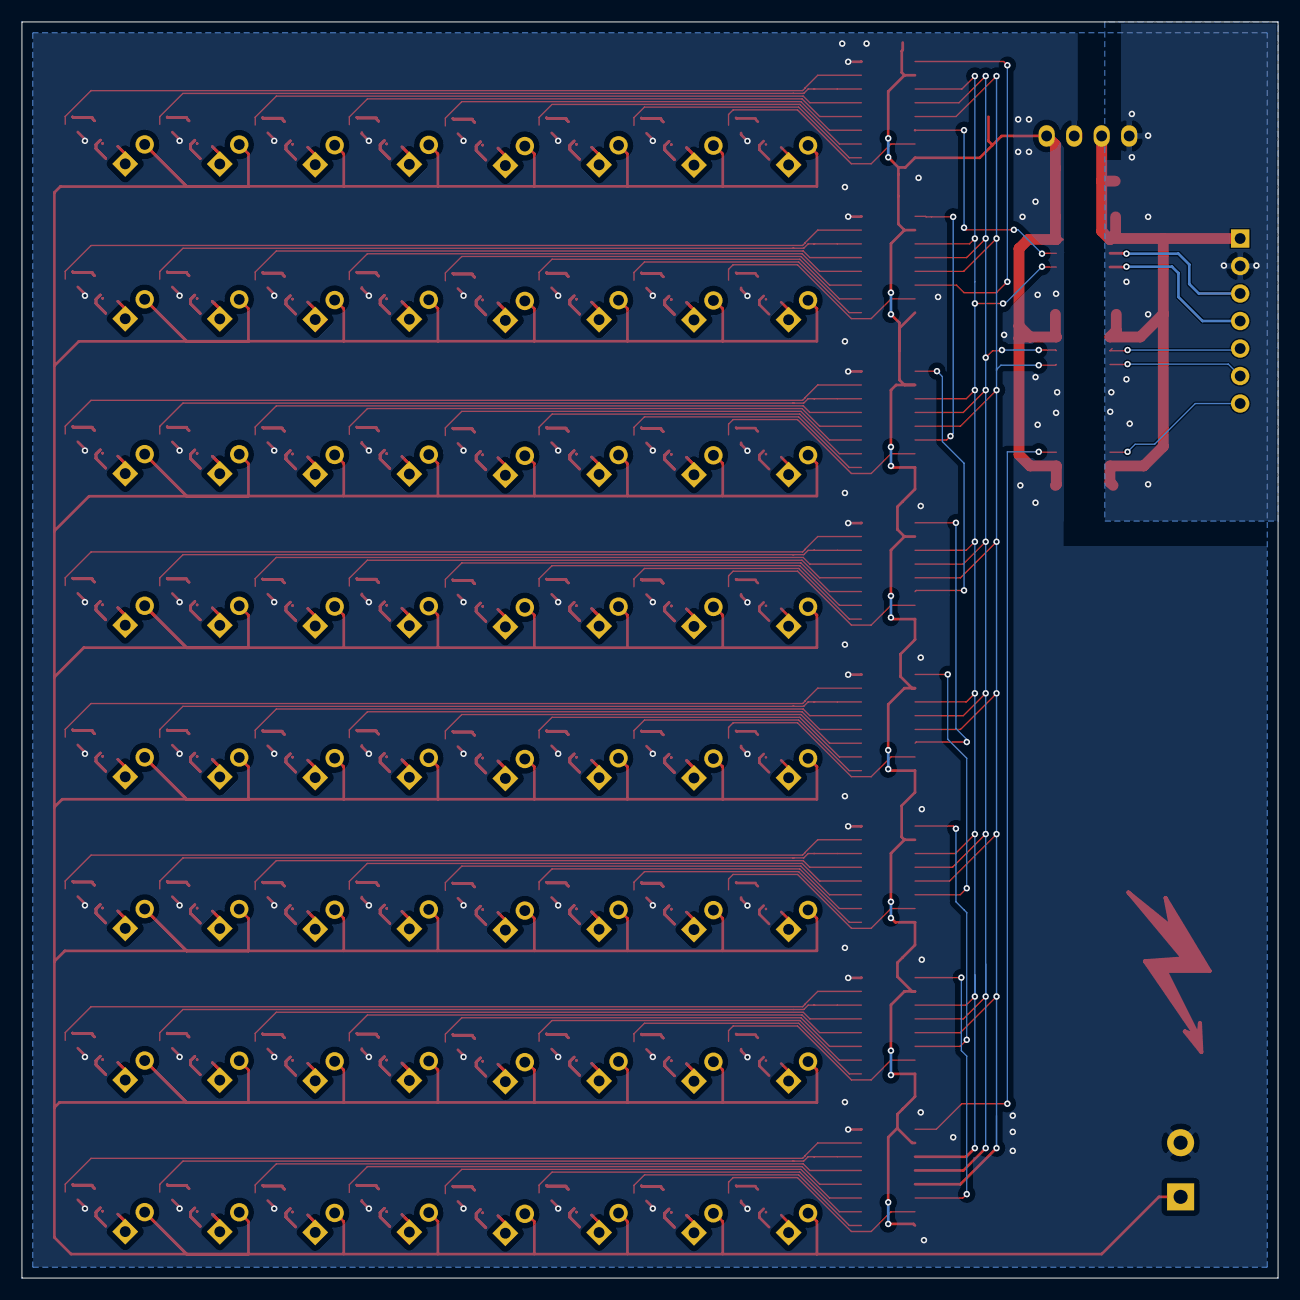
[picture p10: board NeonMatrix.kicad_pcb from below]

Board: 2 copper layers, 116.0 x 116.0 mm, 289 parts (64 on the bottom side), 278 nets.

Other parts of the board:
HV_GND: HV_GND; TestPoint_Pad_2.0x2.0mm
HV_VCC: HV_VCC; TestPoint_Pad_2.0x2.0mm

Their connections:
+3V3: HV_VCC.1; also elsewhere on the board
GND: HV_GND.1; also elsewhere on the board

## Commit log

2020-06-21 First row
    [NeonMatrix.kicad_pcb, NeonMatrix.sch, file595Neon.sch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]
2020-06-23 Add isolation
    [NeonMatrix.kicad_pcb, NeonMatrix.sch, file595Neon.sch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]
2020-06-23 Add routing
    [NeonMatrix.kicad_pcb, NeonMatrix.sch, file595Neon.sch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]
2020-06-23 Add labels to connectors
    [NeonMatrix.kicad_pcb]
2020-06-23 Add PCB markings
    [NeonMatrix.kicad_pcb, NeonMatrix.sch, file595Neon.sch]
2020-06-23 Add bulk capacitance, fix isolation, silkscreen and vias
    [NeonMatrix.kicad_pcb, NeonMatrix.sch, file595Neon.sch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]
2020-07-06 RevA, Add production files
    [NeonMatrix-B_Cu.gbl, NeonMatrix-B_Mask.gbs, NeonMatrix-B_Paste.gbp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]
2020-07-06 Add Readme, Schematic and images
